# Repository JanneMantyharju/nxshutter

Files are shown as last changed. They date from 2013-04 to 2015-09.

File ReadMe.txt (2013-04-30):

This repository contains sources and schematics for Samsung NX camera remote shutter and rc interface
For more information see: http://wp.me/p12J9M-41

Files in this repository:
shutter/ - Source files, compile with arduino
shutter.sch - Schematics for camera cable
rx_switch.sch - Schematics for rc interface

The pin definitions are for AtTiny2313, change them if you use different type of
controller

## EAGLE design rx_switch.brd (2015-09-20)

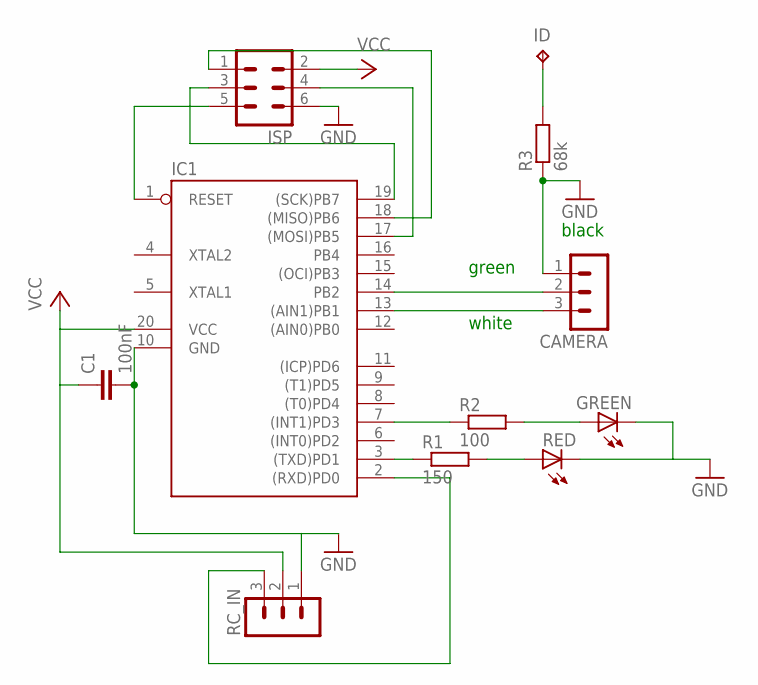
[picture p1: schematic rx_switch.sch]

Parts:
C1: 100nF; C0805
CAMERA: MA03-1
GREEN: LED_E; LED_1206
IC1: AT90S2313S; SO20L
ID: TPPAD1-13; P1-13
ISP: MA03-2
R1: 150; R1206
R2: 100; R1206
R3: 68k; R1206
RC_IN: MA03-1
RED: LED_E; LED_1206

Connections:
GND: C1.2, CAMERA.1, GREEN.C, IC1.10 (GND), ISP.6, R3.1, RC_IN.1, RED.C
ISP: IC1.19 ((SCK)PB7), ISP.3
unnamed: IC1.1 (RESET), ISP.5
unnamed: IC1.17 ((MOSI)PB5), ISP.4
unnamed: IC1.2 ((RXD)PD0), RC_IN.3
unnamed: CAMERA.2, IC1.14 (PB2)
unnamed: CAMERA.3, IC1.13 ((AIN1)PB1)
unnamed: IC1.18 ((MISO)PB6), ISP.1
unnamed: ID.TP, R3.2
unnamed: R1.2, RED.A
unnamed: IC1.7 ((INT1)PD3), R2.1
unnamed: IC1.3 ((TXD)PD1), R1.1
unnamed: GREEN.A, R2.2
VCC: C1.1, IC1.20 (VCC), ISP.2, RC_IN.2

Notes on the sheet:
black
green
white

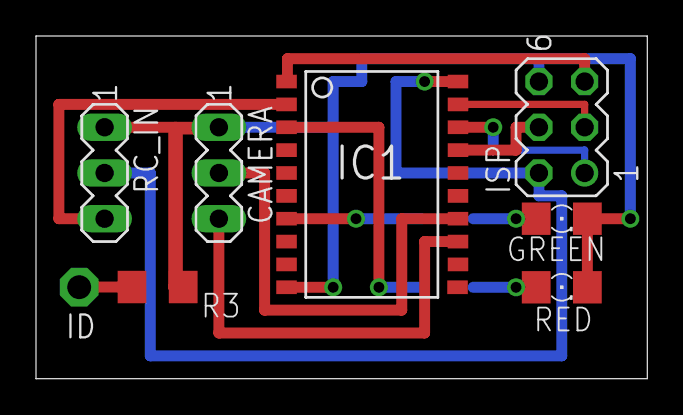
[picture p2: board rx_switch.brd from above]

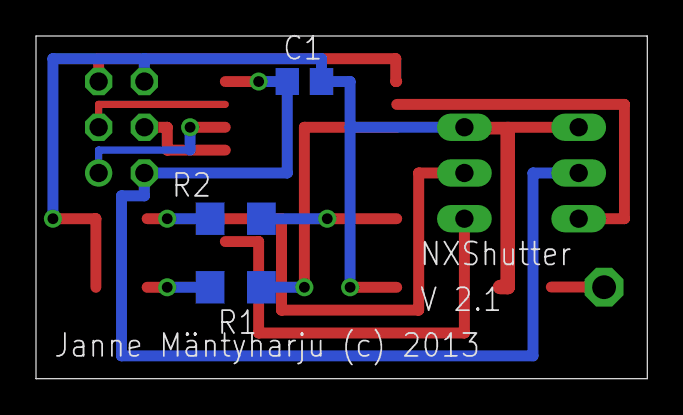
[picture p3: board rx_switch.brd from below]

Board: 2 copper layers, 34.0 x 19.0 mm, 11 parts (3 on the bottom side), 14 nets.

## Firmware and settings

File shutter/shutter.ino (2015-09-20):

/* 
	Shutter control for rc receiver
	(c) Janne Mäntyharju 2013
	
	Pins are for Atmel TINY2313 controller, modify as needed
*/

#define RCIN 0
#define FOCUS 11
#define SHUTTER 10
#define LED_FOCUS 5
#define LED_SHUTTER 1 

#define FOCUS_ACTIVATE 1400
#define SHUTTER_ACTIVATE 1700


void setup()
{
  pinMode(RCIN, INPUT);
  pinMode(FOCUS, INPUT);
  pinMode(SHUTTER, INPUT);
  pinMode(LED_FOCUS, OUTPUT);
  pinMode(LED_SHUTTER, OUTPUT);
  digitalWrite(FOCUS, LOW);
  digitalWrite(SHUTTER, LOW);
  
  digitalWrite(LED_FOCUS, HIGH);
  digitalWrite(LED_SHUTTER, HIGH);
  delay(1000);
  digitalWrite(LED_FOCUS, LOW);
  digitalWrite(LED_SHUTTER, LOW);  
}

void loop()
{
  UCSRB=0;
  int pwm;

  pwm = pulseIn(RCIN, HIGH, 25000);
  if (pwm > FOCUS_ACTIVATE && pwm < SHUTTER_ACTIVATE) {
    pinMode(SHUTTER, INPUT);
    digitalWrite(LED_SHUTTER, LOW); 
    
    pinMode(FOCUS, OUTPUT);
    digitalWrite(LED_FOCUS, HIGH);    
  } else if (pwm > SHUTTER_ACTIVATE) {
    pinMode(FOCUS, INPUT);
    digitalWrite(LED_FOCUS, LOW);
    
    pinMode(FOCUS, OUTPUT);
    delay(100);
    pinMode(SHUTTER, OUTPUT);
    digitalWrite(LED_SHUTTER, HIGH);
  } else {
    pinMode(FOCUS, INPUT);
    digitalWrite(LED_FOCUS, LOW);
    
    pinMode(SHUTTER, INPUT);
    digitalWrite(LED_SHUTTER, LOW); 
  }
}

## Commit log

2013-10-03 Started creating pcb
    [rx_switch.brd, rx_switch.sch]
2013-10-04 PCB design
    [rx_switch.brd, rx_switch.sch]
2013-10-31 PCB revision v.21
    [rx_switch.brd, rx_switch.sch]
2015-09-20 Fixed NX500 / NX2000 support
    [rx_switch.brd, rx_switch.sch]

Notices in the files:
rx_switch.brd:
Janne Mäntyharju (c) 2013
